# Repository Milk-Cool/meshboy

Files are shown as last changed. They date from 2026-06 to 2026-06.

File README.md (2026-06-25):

# meshboy
a meshtastic gameboy cartridge

> **NOTE**: this project is **not in a working state right now**! you might have to fix some things related to the RP2040 because it doesn't work at all on my board :(

> **what works?** -- the HT-CT62 seems to be working perfectly fine, that includes communication over USB as well as WiFi, BLE and LoRa (so Meshtastic works perfectly!!)

> **what doesn't work?** -- the RP2040 and everythijng that relies on it. that means the actual gameboy communication doesn't work at all, you can't even get it to show up in the device list on a PC. i was unable to verify if communication with the HT-CT62 works either because of that.

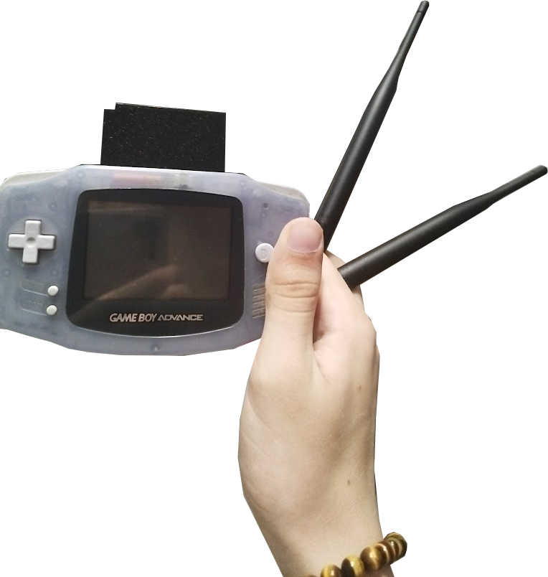
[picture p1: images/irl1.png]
irl photo

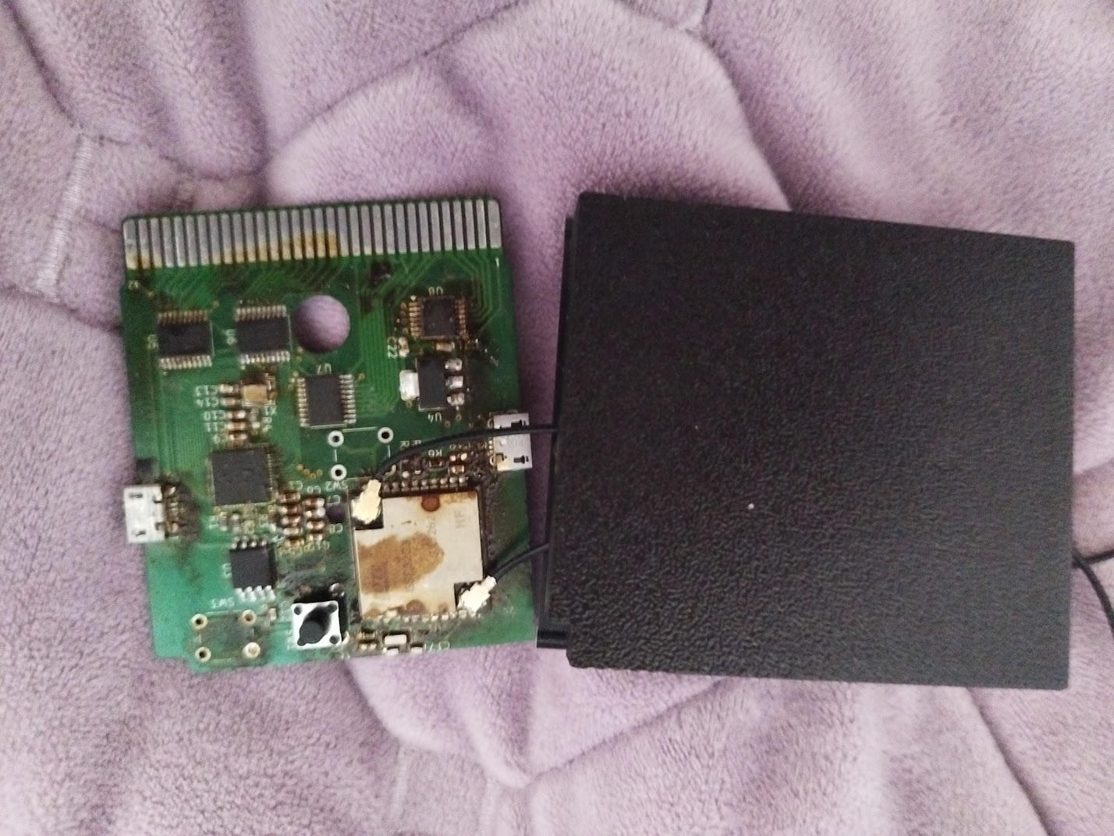
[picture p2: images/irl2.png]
another irl photo


## what is this? what does it do?

this is a cartridge that lets you chat in your local meshtastic network using your gameboy! it's got two antenna slots, first of which has to be a 2.4 ghz antenna and the second of which should be a lora antenna (with the frequency depending on the HT-CT62 model that you use). it's also got a ROM emulator with a custom ROM built specifically for this hardware that allows you to interface with the meshtastic controller chip, which in this case is an ESP32C3! and all of that runs on a gameboy!! isn't that just cool?

anyway here are some pics!!!

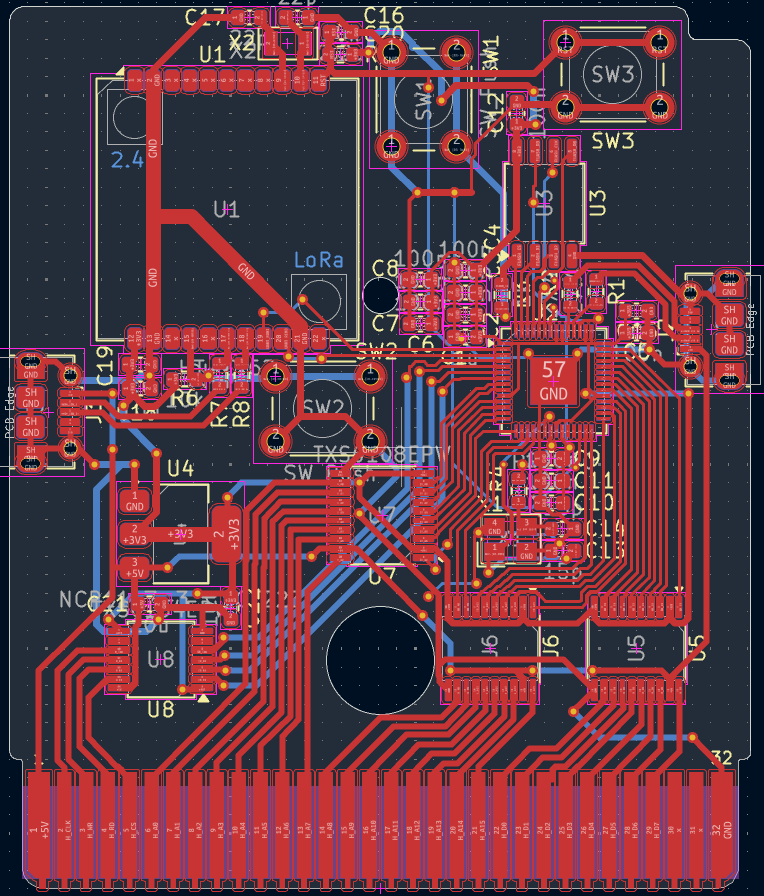
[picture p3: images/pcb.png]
pcb pic


_pcb pic_

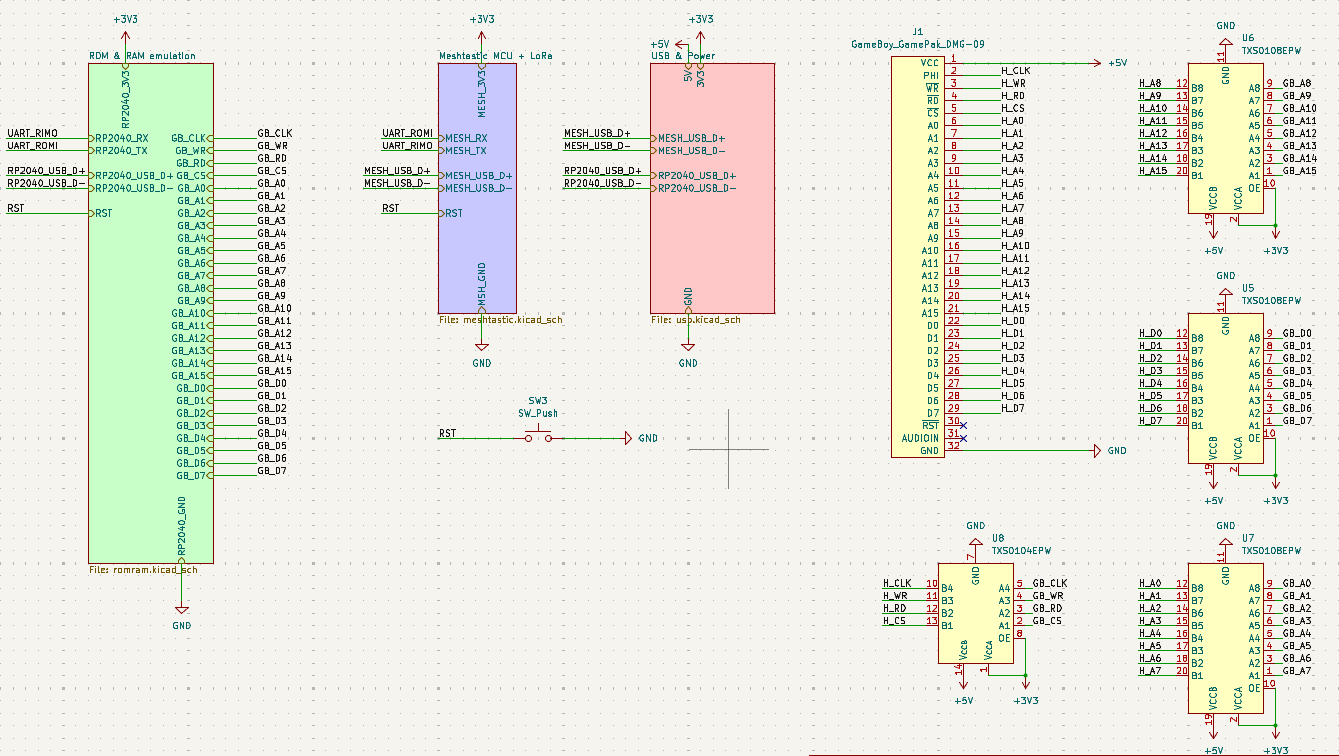
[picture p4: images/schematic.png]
schematic pic


_schematic pic_

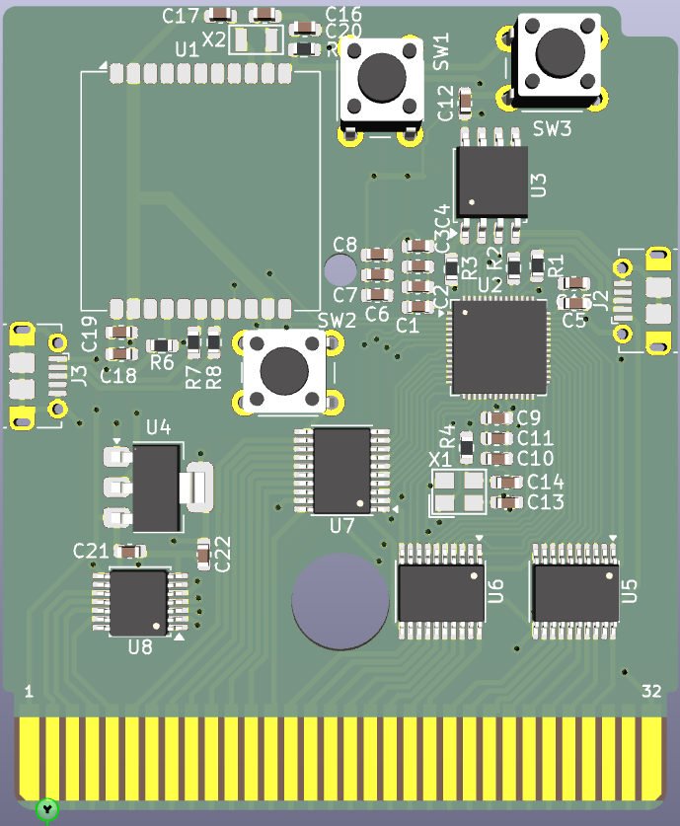
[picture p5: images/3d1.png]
3d render


_3d render_

## how do i build one?

you can build one of these using the provided BOM (`bom.xml`), gerber (`3d/gerbers.zip`) and 3d model files (`3d/`). that should be enough to build your own!! (well, except for the u.fl to sma adapters which you'll have to feed through the holes and attach to the HT-CT62 yourself. that shouldn't be too much of a problem though)

once you have the board you're gonna want to flash it. use the usb ports on the sides along with the appropriate buttons (hold the boot button while resetting or plugging it in):

|button|function|
|-|-|
|SW1|RP2040 bootsel|
|SW2|HT-CT62 bootsel|
|SW3|reset|

> important: do NOT power the boards from both usb ports or the gameboy and a usb port at the same time. there's no protection against that

you can grab the meshtastic firmware from meshtastic's repos (and build it! see `meshtastic/variant.md` for board-specific files) and build this one using platformio (or just grab the binary from `firmware/` and upload it to the RP2040)

don't forget to set `$GBDK_HOME` while compiling the ROM if you wanna make any changes to it! also don't forget to update `rom.h` afterwards

## why this was made

idk seems like a cool idea. i've also never seen anyone do this before, and i thought the gameboy would be the perfect form factor for a meshtastic node :D

## 3d model credits and link
the source for the 3d model is available at https://www.tinkercad.com/things/lLKb2iLMqVb-meshboy?sharecode=PiJsQhaVb8HndL40XNs0V_DODmQBOzxnN_6iqkJiyyc

credits to https://www.printables.com/model/215698-gameboy-cartridge for the original cartridge model!!

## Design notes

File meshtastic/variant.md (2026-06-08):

# `variants/esp32c3/diy/meshboy/platformio.ini`

```ini
[env:meshboy]
extends = esp32c3_base
board = esp32-c3-devkitm-1
build_flags =
  ${esp32c3_base.build_flags}
  -D PRIVATE_HW
  -I variants/esp32c3/diy/meshboy
  -D ARDUINO_USB_MODE=1
  -D ARDUINO_USB_CDC_ON_BOOT=1
board_level = extra
```

# `variants/esp32c3/diy/meshboy/variant.h`

```cpp
// thanks to https://github.com/f4goh/CheapMesh/blob/main/firmware/variant.h !!

#pragma once

#define BUTTON_PIN 9

#define USE_SX1262
#define LORA_SCK 10
#define LORA_MISO 6
#define LORA_MOSI 7
#define LORA_CS 8
#define LORA_DIO0 RADIOLIB_NC
#define LORA_RESET 5
#define LORA_DIO1 3
#define LORA_DIO2 RADIOLIB_NC
#define LORA_BUSY 4
#define SX126X_CS LORA_CS
#define SX126X_DIO1 LORA_DIO1
#define SX126X_BUSY LORA_BUSY
#define SX126X_RESET LORA_RESET
#define SX126X_DIO2_AS_RF_SWITCH
#define SX126X_DIO3_TCXO_VOLTAGE 1.8
```

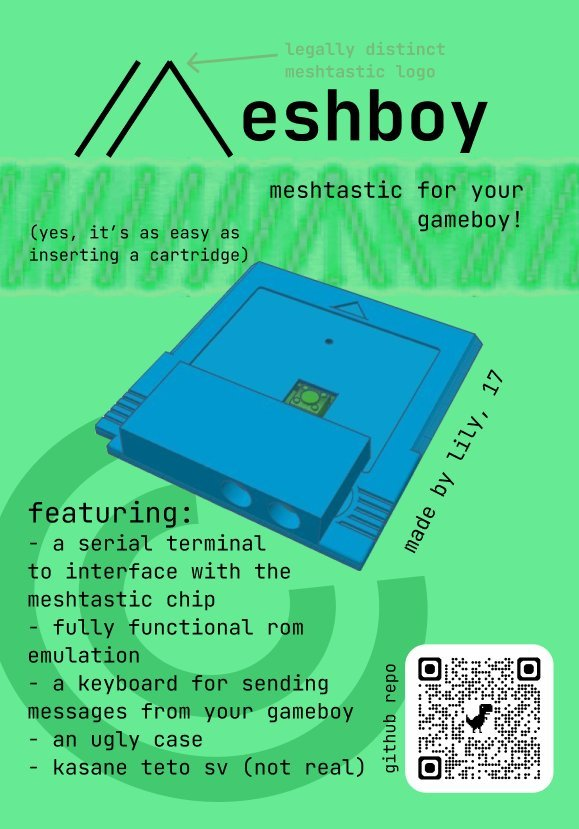
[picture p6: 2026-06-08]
images/zine.png

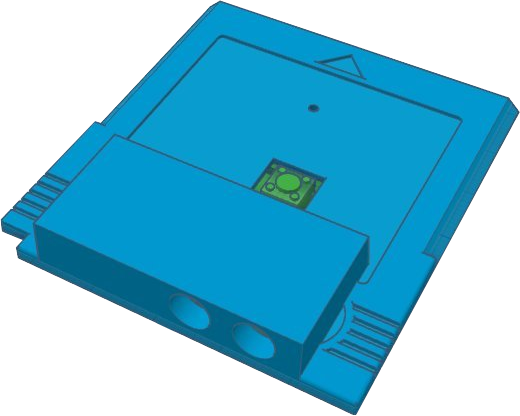
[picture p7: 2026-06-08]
images/3d2.png

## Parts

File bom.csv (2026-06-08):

Reference | Qty | Value | Part no | Link to component | Notes
C1,C9,C19 | 3 | 1u | CC0603KRX7R7BB105 | https://www.lcsc.com/product-detail/C106248.html
C2,C3,C4,C5,C6,C7,C8,C10,C11,C12 | 10 | 100n | CC0603KRX7R7BB104 | https://www.lcsc.com/product-detail/C108079.html
C13,C14 | 2 | 15p | GRM1885C1H150J | https://www.lcsc.com/product-detail/C71651.html
C15,C18,C21,C22 | 4 | 10u | CC0603KRX5R6BB106 | https://www.lcsc.com/product-detail/C326057.html
C16,C17 | 2 | 22p | CC0603JRNPO8BN220 | https://www.lcsc.com/product-detail/C519390.html
C20 | 1 | 2.2u | GRM188R61A225K | https://www.lcsc.com/product-detail/C86013.html
J2,J3 | 2 | USB_B_Micro | Molex-105017-0001 | https://www.lcsc.com/product-detail/C136000.html
R1,R2 | 2 | 27.4 | RC0603FR-0727R4L | https://www.lcsc.com/product-detail/C185346.html
R3,R4 | 2 | 1k | RC0603FR-071KL | https://www.lcsc.com/product-detail/C22548.html
R5,R6 | 2 | 10k | AC0603FR-0710KL | https://www.lcsc.com/product-detail/C116677.html
R7,R8 | 2 | 22 | RC0603JR-0722RL | https://www.lcsc.com/product-detail/C108405.html
SW1,SW2,SW3 | 3 | SW_Push | FG TC-6601-5.0-260-8.3 | https://www.lcsc.com/product-detail/C7528752.html
U1 | 1 | HT-CT62 | Heltec_HT-CT62 | https://www.aliexpress.us/item/3256808178334088.html | Mind the frequency!
U2 | 1 | RP2040 | RP2040 | https://www.lcsc.com/product-detail/C2961140.html
U3 | 1 | W25Q16JVSS | W25Q16JVSS | https://www.lcsc.com/product-detail/C131025.html
U4 | 1 | NCP1117-3.3_SOT223 | NCP1117IST33T3G | https://www.lcsc.com/product-detail/C2902119.html
U5,U6,U7 | 3 | TXS0108EPW | TXS0108EPWR | https://www.lcsc.com/product-detail/C17206.html
U8 | 1 | TXS0104EPW | TXS0104EPWR | https://www.lcsc.com/product-detail/C44955.html
X1 | 1 | DSX321G-12MHZ | DSX321G 12MHZ | https://www.lcsc.com/product-detail/C93234.html
X2 | 1 | NX3215SA-32.768KHZ | NX3215SA-32.768KHZ | https://www.lcsc.com/product-detail/C5136773.html

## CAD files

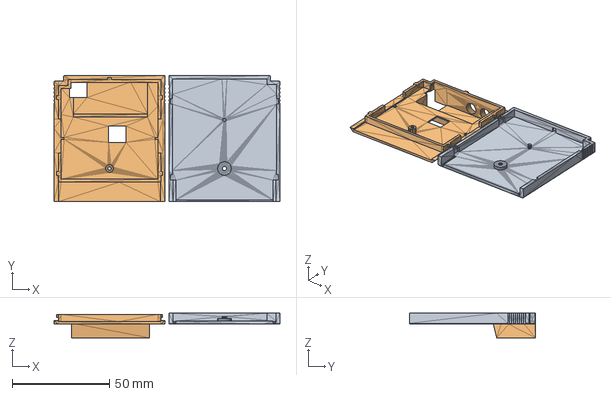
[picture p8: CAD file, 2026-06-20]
3d/meshboy.step
116.0 x 64.8 x 12.7 mm

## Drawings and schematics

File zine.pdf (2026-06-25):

# eshboy

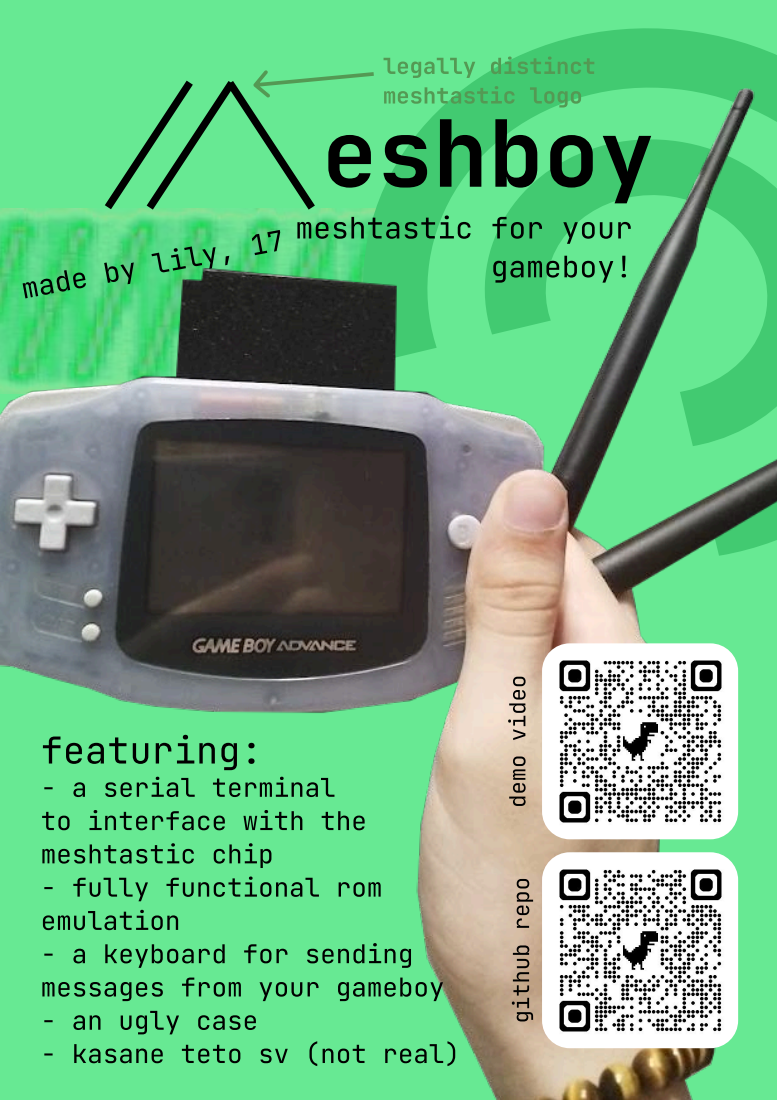
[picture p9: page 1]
legally distinct; meshtastic logo; gameboy!; featuring:

made by lily, 17 meshtastic for your

demo video github repo

- a serial terminal
to interface with the
meshtastic chip
- fully functional rom
emulation
- a keyboard for sending

messages from your gameboy

- an ugly case
- kasane teto sv (not real)

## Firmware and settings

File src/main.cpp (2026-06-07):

// https://dhole.github.io/post/gameboy_cartridge_emu_1/

#include <Arduino.h>
#include "rom.h"

#define GB_CLK 2UL
#define GB_WR 3UL
#define GB_RD 4UL
#define GB_CS 5UL
#define GB_A_MIN 6UL
#define GB_A_MAX 21UL
#define GB_D_MIN 22UL
#define GB_D_MAX 29UL

#define P(x) (1UL << x)
#define GB_A (P(GB_A_MIN + 0) | P(GB_A_MIN + 1) | P(GB_A_MIN + 2) | P(GB_A_MIN + 3) | P(GB_A_MIN + 4) | P(GB_A_MIN + 5) | P(GB_A_MIN + 6) | P(GB_A_MIN + 7) | P(GB_A_MIN + 8) | P(GB_A_MIN + 9) | P(GB_A_MIN + 10) | P(GB_A_MIN + 11) | P(GB_A_MIN + 12) | P(GB_A_MIN + 13) | P(GB_A_MIN + 14) | P(GB_A_MIN + 15))
#define GB_D (P(GB_D_MIN + 0) | P(GB_D_MIN + 1) | P(GB_D_MIN + 2) | P(GB_D_MIN + 3) | P(GB_D_MIN + 4) | P(GB_D_MIN + 5) | P(GB_D_MIN + 6) | P(GB_D_MIN + 7))

uint8_t uart_rx_buf[0x100];
uint8_t uart_tx_buf[0x100];
uint8_t uart_n = 0;

uint8_t ram[0x4000]; // 16KB; could have gotten away with just having the above variable in this one... but it's whatever really

void setup() {
    // we don't care about the time taken to set everything up

    Serial.begin(38400); // default baudrate for meshtastic serial

    pinMode(GB_CLK, INPUT_PULLUP);
    pinMode(GB_WR, INPUT_PULLUP);
    pinMode(GB_RD, INPUT_PULLUP);
    pinMode(GB_CS, INPUT_PULLUP);
    for(int p = GB_A_MIN; p <= GB_A_MAX; p++)
        pinMode(p, INPUT_PULLUP);
    for(int p = GB_D_MIN; p <= GB_D_MAX; p++) {
        pinMode(p, INPUT_PULLUP);
        digitalWrite(p, LOW);
    }
}
uint16_t addr;
uint8_t data;
void loop() {
    // we do care about the loop time tho

    while(!(sio_hw->gpio_in & P(GB_CLK)));
    // a single NOP instruction takes ~8ns
    // also yes, i could not come up with a better way -- macros seem overkill here
    __nop();__nop();__nop();__nop();__nop();__nop();__nop();__nop();__nop();__nop();__nop();__nop();__nop();__nop();__nop();__nop();__nop();__nop();__nop();

    // oh god i'm annotating this a lot
    // tbf i am writing something i barely understand here lol

    if(sio_hw->gpio_in & P(GB_RD)) {
        // write operation (they're inverted lolz)
        sio_hw->gpio_oe_clr |= GB_D;

        while(!(sio_hw->gpio_in & P(GB_WR)));
        addr = (sio_hw->gpio_in & (P(GB_A_MAX + 1) - 1)) >> GB_A_MIN; // a very convoluted way to read just the address pins
        while(sio_hw->gpio_in & P(GB_CLK)); // waiting for clock fall to read the data
        data = (sio_hw->gpio_in & (P(GB_D_MAX + 1) - 1)) >> GB_D_MIN;
        if(addr >= 0xa200 && addr < 0xa300) uart_tx_buf[addr - 0xa200] = data; // set data to write to esp32
        else if(addr == 0xa300) uart_n = Serial.readBytes(uart_rx_buf, data); // read data from esp32
        else if(addr == 0xa301) Serial.write(uart_tx_buf, data); // send data to esp32
        else if(addr >= 0xa000 && addr < 0xe000) ram[addr - 0xa000] = data; // writing to ram
    } else {
        // read operation
        sio_hw->gpio_oe_set |= GB_D;

        addr = (sio_hw->gpio_in & (P(GB_A_MAX + 1) - 1)) >> GB_A_MIN;
        if(addr >= 0xa100 && addr < 0xa200) data = uart_rx_buf[addr - 0xa100]; // reading from read data buffer
        else if(addr == 0xa302) data = uart_n; // read data byte count
        else if(addr >= 0x0000 && addr < 0x4000) data = rom[addr]; // reading from rom
        else if(addr >= 0xa000 && addr < 0xe000) data = ram[addr - 0xa000]; // reading from ram
        else data = 0; // fallback
        // (sio_hw->gpio_in & (P(GB_D_MAX + 1) - 1)) >> GB_D_MIN;
        sio_hw->gpio_out &= (~(P(GB_D_MAX + 1) - 1)) ^ (~(P(GB_D_MIN + 1) - 1)); // an even more convoluted way of clearing the state of all the unneeded pins
        sio_hw->gpio_out |= data << GB_D_MIN;
        while(sio_hw->gpio_in & P(GB_CLK)); // waiting for clock fall for the next iteration
    }
}

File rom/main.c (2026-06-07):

#include <gb/gb.h>
#include <gb/drawing.h>
#include <stdint.h>

#pragma dataseg DATA_0

#define RX_BUF ((uint8_t*)0xa100)
#define TX_BUF ((uint8_t*)0xa200)
#define RX_INST ((uint8_t*)0xa300)
#define TX_INST ((uint8_t*)0xa301)
#define RX_NUM ((uint8_t*)0xa302)

uint8_t cur_mode = 0;

uint8_t v, l = 0;
#define PRESSED(x) ((v & x) && !(l & x))

char message[64];
uint8_t message_length = 0;
uint8_t char_idx;

void clear(void) {
    gotogxy(0, 0);
    for(uint8_t y = 0; y < GRAPHICS_HEIGHT / 8; y++)
        for(uint8_t x = 0; x < GRAPHICS_WIDTH / 8; x++)
            wrtchr(' ');
}

char get_ch(uint8_t x, uint8_t y) {
    if(x < 2 || x >= 18) return ' ';
    if(y < 1 || y >= 17) return ' ';
    uint8_t i = (y - 1) * 16 + x - 2;
    if(i >= 0x90 && i - 0x90 < message_length) return message[i - 0x90];
    if(i < 0x20 || i >= 0x7f) return ' ';
    return (char)i;
}
uint8_t get_x(void) {
    return (char_idx & 15) + 2;
}
uint8_t get_y(void) {
    return (char_idx >> 4) + 1;
}
void init_kb(void) {
    cur_mode = 1;
    char_idx = 0x20;
    message_length = 0;
    gotogxy(0, 0);
    for(uint8_t y = 0; y < GRAPHICS_HEIGHT / 8; y++)
        for(uint8_t x = 0; x < GRAPHICS_WIDTH / 8; x++) {
            if(x == get_x() && y == get_y()) color(WHITE, BLACK, SOLID);
            else color(BLACK, WHITE, SOLID);
            wrtchr(get_ch(x, y));
        }
}
void serial(void) {
    *RX_INST = 255;
    uint8_t n = *RX_NUM;
    for(uint16_t i = 0; i < n; i++)
        wrtchr(RX_BUF[i]);
    
    if(PRESSED(J_B))
        clear();
    else if(PRESSED(J_A))
        init_kb();
}
void keyboard(void) {
    uint8_t last = char_idx;
    uint8_t lx = get_x(), ly = get_y();
    if(PRESSED(J_LEFT)) char_idx--;
    if(PRESSED(J_RIGHT)) char_idx++;
    if(PRESSED(J_UP)) char_idx -= 16;
    if(PRESSED(J_DOWN)) char_idx += 16;
    if(char_idx < 0x20) char_idx += 0x5f;
    if(char_idx >= 0x7f) char_idx -= 0x5f;
    if(char_idx != last) {
        color(WHITE, BLACK, SOLID);
        gotogxy(get_x(), get_y());
        wrtchr(get_ch(get_x(), get_y()));
        color(BLACK, WHITE, SOLID);
        gotogxy(lx, ly);
        wrtchr(get_ch(lx, ly));
    }

    if(PRESSED(J_SELECT)) {
        clear();
        cur_mode = 0;
    } else if(PRESSED(J_START)) {
        clear();
        cur_mode = 0;

        for(uint8_t i = 0; i < message_length; i++)
            TX_BUF[i] = message[i];
        *TX_INST = message_length;
    } else if(PRESSED(J_A) && message_length < 64) {
        char c = get_ch(get_x(), get_y());

        gotogxy((message_length & 15) + 2, (message_length >> 4) + 10);
        wrtchr(c);

        message[message_length] = c;
        message_length++;
    } else if(PRESSED(J_B) && message_length > 0) {
        message_length--;
        gotogxy((message_length & 15) + 2, (message_length >> 4) + 10);
        wrtchr(' ');
    }
}

void main(void) {
    ENABLE_RAM;
    // SWITCH_RAM(0);

    // Loop forever
    while(1) {
        v = joypad();
        if(cur_mode) keyboard();
        else serial();
        vsync();
        l = v;
    }
}

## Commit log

2026-06-08 add 3d model
    [meshboy.step]
2026-06-08 readme, bom and pcb project files with gerbers
    [bom.csv, meshboy.kicad_pcb, meshboy.kicad_sch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]
2026-06-15 oops i didn't realize i put kicad files into `3d/`
    [meshboy.kicad_pcb, meshboy.kicad_sch, meshboy.sch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]
2026-06-20 add step file
    [meshboy.step]
